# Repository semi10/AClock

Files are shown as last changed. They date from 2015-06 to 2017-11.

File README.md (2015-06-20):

AClock - Dot Matrix Display Information Board
Based on ATmega328P (Arduino)

Main Components:
Bicolor Red & Green LED 5mm Dot Matrix Display: http://store.sure-electronics.com/led/led-display/de-dp14211
RTC DS1307: http://datasheets.maximintegrated.com/en/ds/DS1307.pdf
EEPROM 24LC256: https://www.sparkfun.com/products/525
Humidity and Temperature Sensor RHT03: https://www.sparkfun.com/products/10167

Some Features:

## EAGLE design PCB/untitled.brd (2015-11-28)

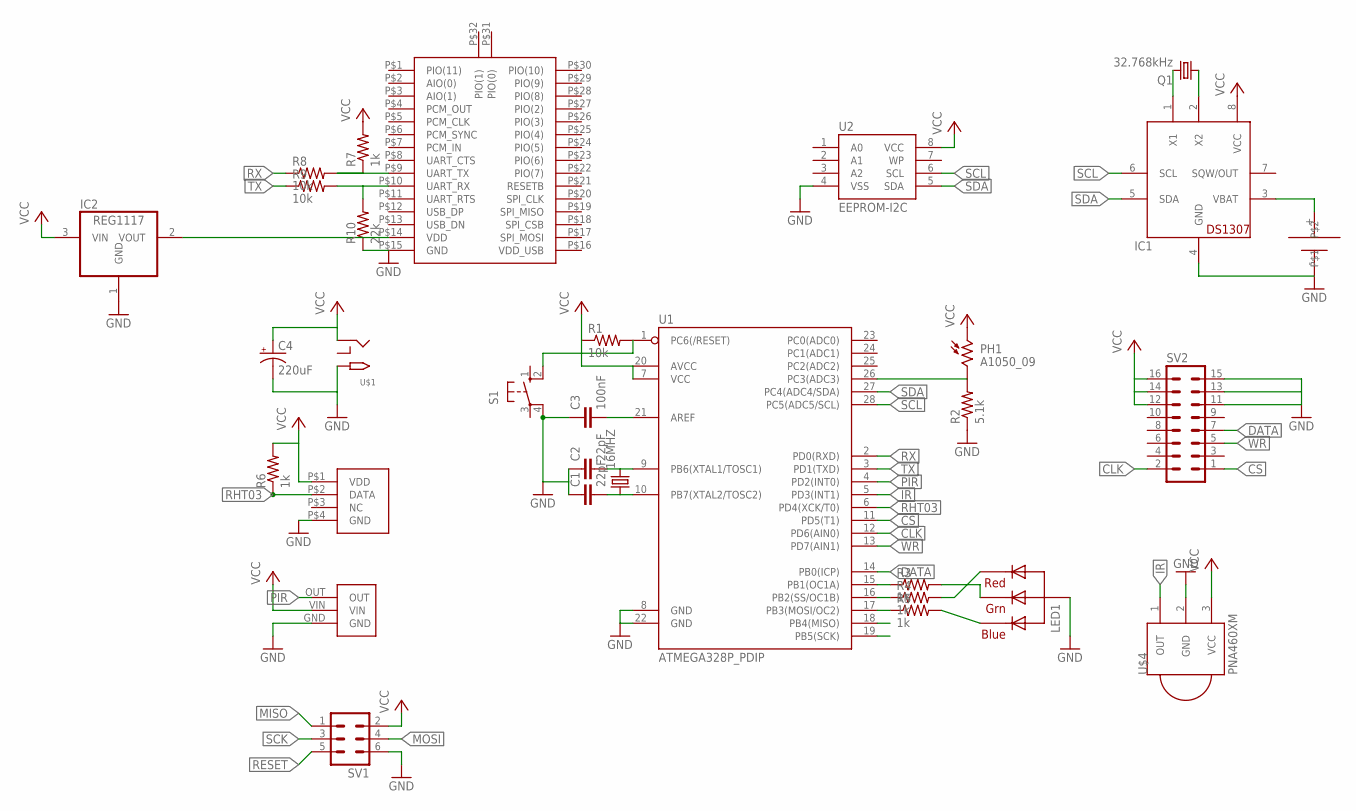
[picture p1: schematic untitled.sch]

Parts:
16MHZ: CRYSTALHC49U-H; HC49U-H
C1, C2: 22pF; C025-024X044
C3: 100nF; C025-024X044
C4: 220uF; E3,5-8
IC1: DS1307; DIL08
IC2: REG1117; SOT223
LED1: RGBLED_CA-5MM; LED5MMRGB
PH1: A1050_09; T0-46-A10XX
Q1: 32.768kHz; TC38H
R1, R8, R9: 10k; 0207/10
R2: 5.1k; 0207/10
R3, R4, R5, R6, R7: 1k; 0207/10
R10: 22k; 0207/10
S1: 10-XX; B3F-10XX
SV1: ML6
SV2: ML16
U1: ATMEGA328P_PDIP; DIL28-3
U2: EEPROM-I2C; DIL08
U$1: 2.1MMJACK; 2.1MMJACK_BREADBOARD
U$2: RHT03THROUGH_HOLE; RHT03
U$3: PIR_PM-6; PIR_THROUGHHOLE
U$4: PNA460XM
U$5: CR2032; CR2032-THM
U$6: BTM-182

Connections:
CLK: SV2.2, U1.12 (PD6(AIN0))
CS: SV2.1, U1.11 (PD5(T1))
DATA: SV2.7, U1.14 (PB0(ICP))
GND: C1.1, C2.1, C3.1, C4.-, IC1.4 (GND), IC2.1 (GND), LED1.2 (VCC), R2.1, R10.1, S1.4 (P1), SV1.6, SV2.11, SV2.13, SV2.15, U1.8 (GND), U1.22 (GND), U2.4 (VSS), U$1.GND (TIP), U$2.P$4 (GND), U$3.GND, U$4.2 (GND), U$5.-, U$6.P$15 (GND)
IR: U1.5 (PD3(INT1)), U$4.1 (OUT)
MISO: SV1.1, U1.18 (PB4(MISO))
MOSI: R5.1, SV1.4, U1.17 (PB3(MOSI/OC2))
unnamed: 16MHZ.1, C1.2, U1.10 (PB7(XTAL2/TOSC2))
unnamed: 16MHZ.2, C2.2, U1.9 (PB6(XTAL1/TOSC1))
unnamed: C3.2, U1.21 (AREF)
unnamed: R4.1, U1.16 (PB2(SS/OC1B))
unnamed: R3.1, U1.15 (PB1(OC1A))
unnamed: PH1.2, R2.2, U1.26 (PC3(ADC3))
unnamed: IC1.3 (VBAT), U$5.+
unnamed: IC2.2 (VOUT), U$6.P$14 (VDD)
unnamed: LED1.1 (RED), R4.2
unnamed: LED1.3 (GREEN), R3.2
unnamed: LED1.4 (BLUE), R5.2
unnamed: IC1.1 (X1), Q1.2
unnamed: IC1.2 (X2), Q1.1
unnamed: R7.1, R8.2, U$6.P$9 (UART_TX)
unnamed: R9.2, R10.2, U$6.P$10 (UART_RX)
PIR: U1.4 (PD2(INT0)), U$3.OUT
RESET: R1.2, S1.2 (S1), SV1.5, U1.1 (PC6(/RESET))
RHT03: R6.1, U1.6 (PD4(XCK/T0)), U$2.P$2 (DATA)
RX: R8.1, U1.2 (PD0(RXD))
SCK: SV1.3, U1.19 (PB5(SCK))
SCL: IC1.6 (SCL), U1.28 (PC5(ADC5/SCL)), U2.6 (SCL)
SDA: IC1.5 (SDA), U1.27 (PC4(ADC4/SDA)), U2.5 (SDA)
TX: R9.1, U1.3 (PD1(TXD))
VCC: C4.+, IC1.8 (VCC), IC2.3 (VIN), PH1.1, R1.1, R6.2, R7.2, SV1.2, SV2.12, SV2.14, SV2.16, U1.7 (VCC), U1.20 (AVCC), U2.8 (VCC), U$1.PWR (RING), U$2.P$1 (VDD), U$3.VIN, U$4.3 (VCC)
WR: SV2.5, U1.13 (PD7(AIN1))

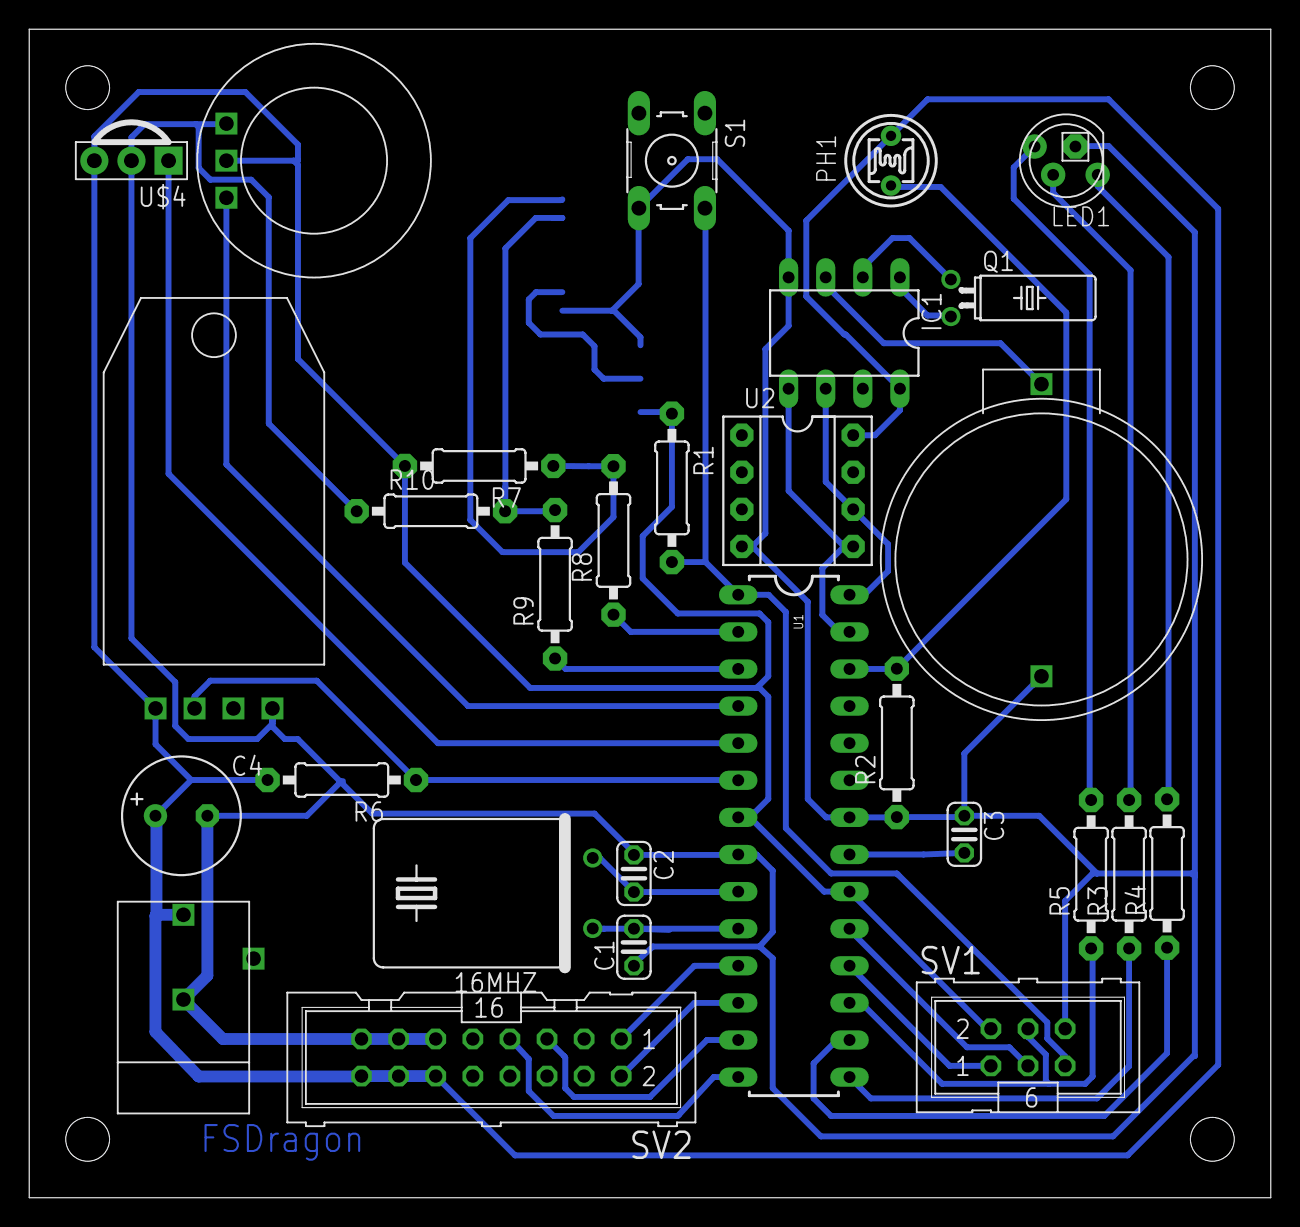
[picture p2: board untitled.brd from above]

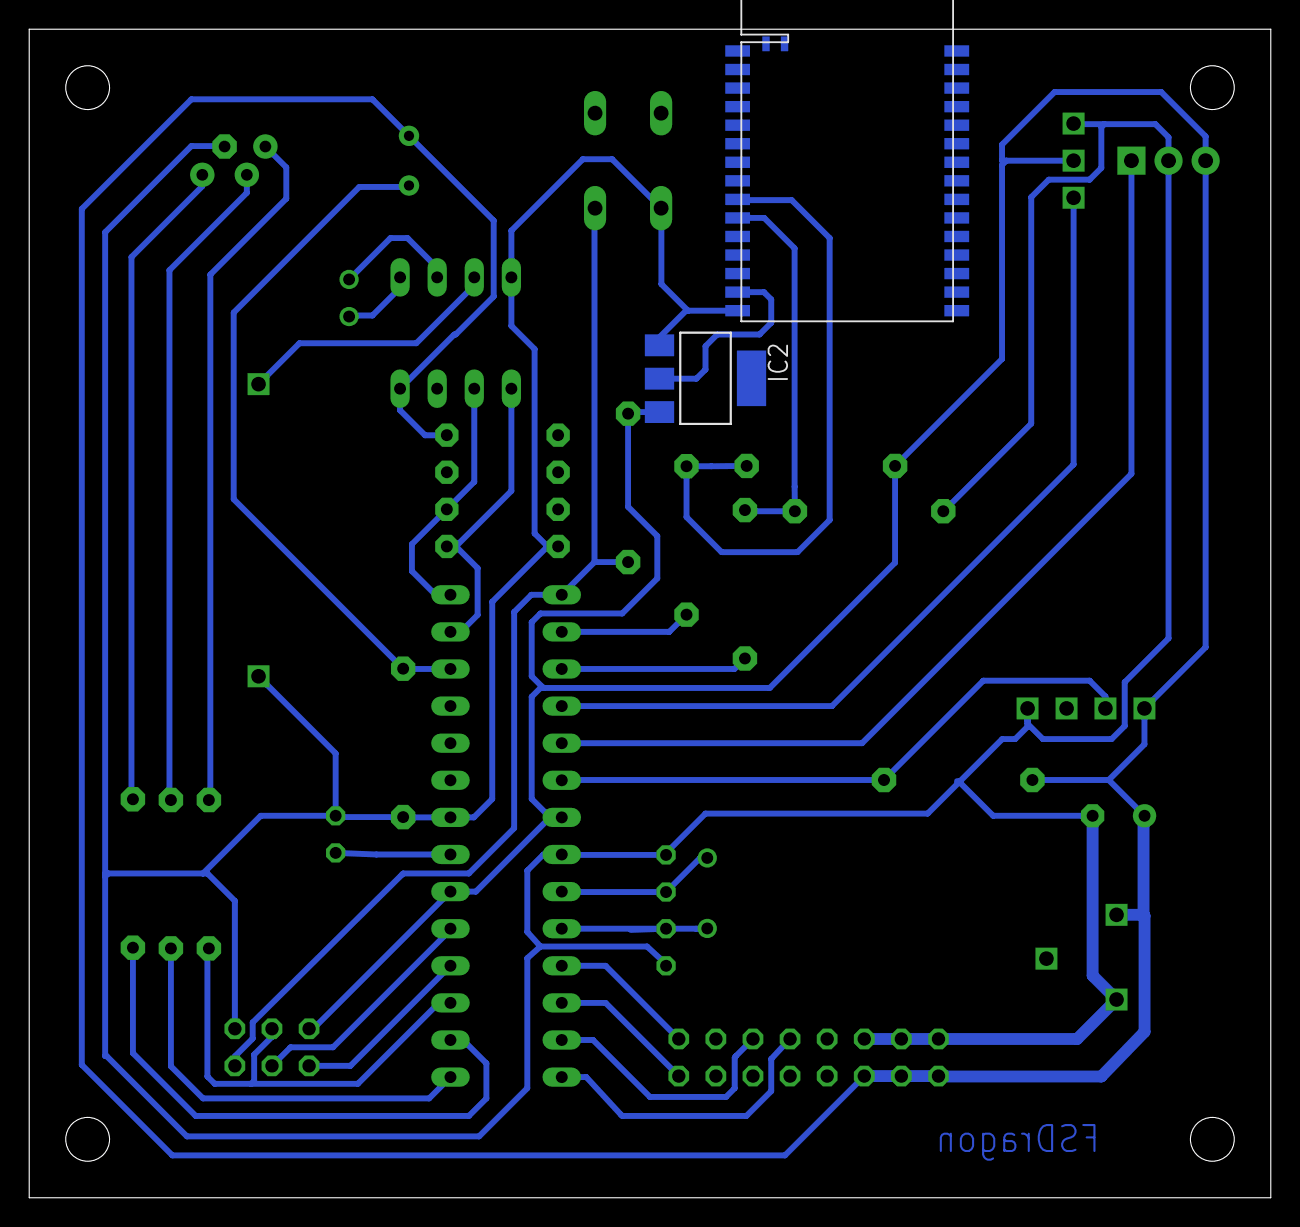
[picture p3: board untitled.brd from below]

Board: 1 copper layer, 85.0 x 80.0 mm, 31 parts (2 on the bottom side), 32 nets.

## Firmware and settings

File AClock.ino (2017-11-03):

#include <EEPROM.h>
#include <Wire.h>
#include <avr/wdt.h>
#include <avr/io.h>
#include "RTClib.h"
#include "I2CRom.h"
#include "ht1632c.h"
#include "RHT03.h"
#include "IR.h"
#include "ProgressBar.h"


#define IRpin 3   //Digital
#define LDRPin 3  //Analog
#define red 9
#define green 10
#define blue 11
#define bluetoothStatus 16

ht1632c Board1(5, 6, 7, 0); //(CS, CLK, WR, DATA, NC, NC, GND, VCC) -> (CS,CLK,WR - Port D , DATA - Port B)
RHT03 TH(4);  //Temperature & Humidity sensor
RTClib RTC;   //Real Time Clock
I2CRom Rom;
IR  IR1(IRpin);                  // IR remote
ProgressBar ProgressBar1(&Board1);
boolean statusLed[3] = {0, 1, 0}; // [R,G,B]
boolean sleep = false;
volatile boolean standBy = false;    //No movement registered in last ~20 minutes

boolean DateMode = false;
boolean HumidityMode = true;
boolean TemperatureMode = true;

void setup() {
  Serial.begin(19200);
  Board1.resetBoard();
  attachInterrupt(digitalPinToInterrupt(IRpin), initIRInterrupt, CHANGE);  //PIR
  pinMode(bluetoothStatus, INPUT);
  Board1.print("Debug", 0, 'g');
  delay(5000);
}

void loop() {

  UpdateTime();

  if (IR1.available()){
    receiveIR();
  }
  if (bluetoothStatus){
    
  }
  
  adjustBrightness();

  if (Board1.scrolling) Board1.scroll(1, 100);
  else if (!standBy) ModeSelect();

  if (Serial.available() > 0) getData();
  if (ProgressBar1.getInProgress()) ProgressBar1.animateProgress();

}

/******************************************************************
    Update Time and date on Display (if it turned on)
*/
void UpdateTime() {
  static unsigned long lastTimeUpdate;
  String time, hour, minute;
  static int column; // colon column

  //Executed each minute
  if (RTC.timeChanged()) {

    RTC.getTime(hour, minute);
    time = hour + ':' + minute;
    column = Board1.print(time , 0 , 'g', ':');
    blink(column, true);

    // Turn on display in the morning
    if (hour == "06" && minute == "40" && standBy == true) {
      sleep = false;
      if (!standBy) Board1.turnOn();
    }

    if (RTC.getMinute() == 0) log(); //Write to log each hour

    lastTimeUpdate = millis();

    ProgressBar1.redraw();
    //    //Progress Bar refresh
    //    if (progressBar != 0) {
    //      int tempBar = progressBar;
    //      progressBar = 0;
    //      updateProgress(tempBar);
    //    }

  }
  else if (abs(millis() - lastTimeUpdate) > 62000) {
    Board1.print("??:??", 0, 'r');
  }
  else {
    blink(column, false);
  }



}


/******************************************************************
    Select which data to show
*/
void ModeSelect() {
  static byte Mode;
  static unsigned long lastModeChange;

  if (abs(millis() - lastModeChange) > 3000) {
    lastModeChange = millis();

    for (int m = 0; m < 4; m++) {
      if (Mode == 0 && DateMode) {
        Board1.print(RTC.getDate(), 1, 'g');
        Mode++;
        break;
      }
      else if (Mode == 1 && HumidityMode) {
        Board1.print("H:" + (String)TH.getHumidity() + "%" , 1, 'g');
        Mode++;
        break;
      }
      else if (Mode == 2 && TemperatureMode) {
        Board1.print("T:" + (String)TH.getTemperature() + "C", 1, 'g');
        Mode++;
        break;
      }
      else {
        Mode++;
        if (Mode > 2) Mode = 0;
      }
    }
  }
}

/******************************************************************
    Get Data from Serial Port
*/

void getData() {
  String serIn;
  char character;
  char temp[3]; //for string to number convertion


    while (Serial.available()) {
      delay(6);
      character = Serial.read();
      serIn.concat(character);
      if (character == '\n') break;
    }

  Serial.println(serIn);

  if (serIn.startsWith("c:")) { //c: for clock adjust - Time Format: "c: dd/mm/yy hh:mm:ss PM" <-(or AM)
    RTC.setTime(serIn);
  }
  else if (serIn.startsWith("c?")) {
    Serial.print(RTC.getDay());
    Serial.print("/");
    Serial.print(RTC.getMonth());
    Serial.print("/");
    Serial.print(RTC.getYear());
    Serial.print(" ");
    Serial.print(RTC.getHour());
    Serial.print(":");
    Serial.print(RTC.getMinute());
    Serial.print(":");
    Serial.println(RTC.getSec());
  }
  else if (serIn.startsWith("p:")) { //p: for print text
    if (serIn.lastIndexOf('\r') != -1) serIn.remove(serIn.lastIndexOf('\r')); //remove new line char
    Board1.print(serIn.substring(3, serIn.length()), 1, 'g');
  }
  else if (serIn.startsWith("m?")) { //m? for mode check
    delay(100);
    Serial.println("mode: " + String(DateMode |  (HumidityMode << 1) | (TemperatureMode << 2), BIN));
  }
  else if (serIn.startsWith("m:")) { //m: for mode change
    serIn = serIn.substring(3, serIn.length());
    serIn.toCharArray(temp, serIn.length() + 1);
    DateMode = atoi(temp) & 1;
    HumidityMode = atoi(temp) & 2;
    TemperatureMode = atoi(temp) & 4;
  }
  else if (serIn.startsWith("\r\nCONNECT")) {
    statusLed[0] = 0;  //R
    statusLed[1] = 0;  //G
    statusLed[2] = 1;  //B
  }
  else if (serIn.startsWith("\r\nDISCONNECT")) {
    statusLed[0] = 0;  //R
    statusLed[1] = 1;  //G
    statusLed[2] = 0;  //B
    ProgressBar1.clear();
    ProgressBar1.setInProgress(false);
  }
  else if (serIn.startsWith("rom?")) {  //rom? for rom read
    int progress = 0;
    Board1.print("R.O.M", 0, 'g');
    Board1.print("Read", 1, 'g');
    for (int day = 0; day < 642; day++) { //day < 642
      for (int column = 0; column < 51; column++) {
        Serial.print(Rom.read(day * 51 + column));
        Serial.print(" ");

        if ((day * 51 + column) % 512 == 0) {
          if (progress < 32) Board1.point(progress, 7, 'r');
          else Board1.point(progress - 32, 7, 'o');
          progress += 1;
        }
      }
      Serial.println();
    }
    Board1.resetBoard();
    Board1.print(RTC.getTime(), 0, 'g');
  }
  else if (serIn.startsWith("t:")) { //t: for time (progress bar)
    int newVal = serIn.substring(3, serIn.length()).toInt();
    if (newVal < ProgressBar1.getVal()) ProgressBar1.clear();
    ProgressBar1.set(newVal);
  }
  else if (serIn.startsWith("s:")) { //s: for state (play/pause/stop)
    int state = serIn.substring(3, serIn.length()).toInt();

    switch (state) {
      case 0: //Stopped
        ProgressBar1.setInProgress(false);
        ProgressBar1.clear();
        break;
      case 1: //Paused
        ProgressBar1.setInProgress(false);
        ProgressBar1.redraw();
        break;
      case 2: //Playing
        ProgressBar1.setInProgress(true);
        break;
    }
  }
}

/******************************************************************
    Write temperature & humidity values to ROM
*/
void log() {
  int address = 0x00;
  int startDay = Rom.read(0x00);
  int startMonth = Rom.read(0x01);
  int startYear = Rom.read(0x02);
  int currentHour = RTC.getHour();
  int currentDay = RTC.getDay();
  int currentMonth = RTC.getMonth();
  int currentYear = RTC.getYear();
  int current_date2days = RTC.date2days(currentDay, currentMonth, currentYear);
  int start_date2days = RTC.date2days(startDay, startMonth, startYear);

  if (startDay > 31 || startDay < 0 || startMonth > 12 || startMonth < 0 || startYear > 99 || startYear < 15 || //Junk data
      address > 32741 || current_date2days < start_date2days) {  //Rom memory exceeded or time error
    address = 0x00;
  }
  else {
    address = (RTC.date2days(currentDay, currentMonth, currentYear) - RTC.date2days(startDay, startMonth, startYear)) * 51;
  }

  if ((Rom.read(address) != currentDay) || (Rom.read(address + 1) != currentMonth) || (Rom.read(address + 2) != currentYear)) { //Clean row for new data
    Rom.write(address, currentDay);
    Rom.write(address + 1, currentMonth);
    Rom.write(address + 2, currentYear);

    for (int i = address + 3; i < 51; i++) {
      Rom.write(i, 0xff);
    }
  }

  address += currentHour * 2 + 3;

  Rom.write(address, TH.getTemperature());
  Rom.write(address + 1, TH.getHumidity());
}

/******************************************************************
     Creates 2 blinking Dots to show the activity of the clock
     column - of blinking dots
     sync - to syncronize time update with blinking
*/
void blink(int column, bool sync) {
  static unsigned long lastBlink;

  if (millis() - lastBlink < 500) {
    Board1.point(column, 2, 'g');
    Board1.point(column, 4, 'g');
  }
  else if (millis() - lastBlink > 1000 || sync) {
    lastBlink = millis();
  }
  else {
    Board1.point(column, 2, 'b');
    Board1.point(column, 4, 'b');
  }
}


/******************************************************************
     Adjust brightness of the board & status LED by reading ambient light sensor
*/
void  adjustBrightness() {
  static unsigned long lastCheck;
  byte PWMBoard, PWMLed;

  if (millis() - lastCheck < 1000) return;
  int LDR = analogRead(LDRPin);

  PWMBoard = map(LDR, 0, 1024, 0, 15);
  Board1.setBrightness(PWMBoard);

  PWMLed = map(LDR, 0, 1024, 1, 30);
  analogWrite(red, statusLed[0] * PWMLed);
  analogWrite(green, statusLed[1] * PWMLed);
  analogWrite(blue, statusLed[2] * PWMLed);

  lastCheck = millis();
}


/******************************************************************
     Go to stand by mode OR wake Up
*/

void goToStandBy() {
  standBy = true;
  attachInterrupt(0, wakeUp, RISING);
  Board1.turnOff();
}

void wakeUp() {
  standBy = false;
  attachInterrupt(0, goToStandBy, FALLING);
  if (!sleep) Board1.turnOn();
}

/******************************************************************
     Receive IR signal
*/
void receiveIR() {
  // char IRcommand;
  // IRcommand =  IR.receive();

  switch (IR1.getCommand()) {
    case 'P':
      static unsigned long lastPress;
      if (millis() - lastPress > 500) {
        lastPress = millis();
        if (sleep) {
          sleep = false;
          if (!standBy) Board1.turnOn();
        }
        else {
          sleep = true;
          Board1.turnOff();
        }
      }
      break;
    case 'L':
      Serial.print("L");    //Louder
      break;
    case 'Q':
      Serial.print("Q");     //Quiet
      break;
    case '+':
      Serial.print("+");
      break;
    case '-':
      Serial.print("-");
      break;
      // default:
      // Serial.println("Error");   //Error
  }

}

//Init IR Interrupt
void initIRInterrupt(){
  IR1.receiveBit();
}

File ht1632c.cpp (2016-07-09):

/******************************************************************
   Nov, 2008 by Bill Westfield ("WestfW")
   Copyrighted and distributed under the terms of the Berkely license
   (copy freely, but include this notice of original author.)

   May, 2011 edited by Semion Faifman for SURE electronics 32X16 RG Bicolor LED Dot Matrix Unit Board
*/
#include "ht1632c.h"                     // Holtek LED driver by WestFW - updated to HT1632C by Nick Hall
#include <avr/pgmspace.h>                // Enable data to be stored in Flash Mem as well as SRAM              
#include "NewFont.h"                     // Font library
#include <Arduino.h>
#define led1 8
#define led2 9
#define led3 10
#define led4 11

ht1632c::ht1632c(byte ht1632_cs, byte ht1632_clk, byte ht1632_wrclk, byte ht1632_data) {
  _ht1632_cs = ht1632_cs;		//Chip select signal input
  _ht1632_clk = ht1632_clk;		//Chip select clock signal input
  _ht1632_wrclk = ht1632_wrclk;	        //Write data clock input
  _ht1632_data = ht1632_data;		//Data input

  DDRD |= (1 << _ht1632_cs);       //ht1632_cs as output
  DDRD |= (1 << _ht1632_clk);      //_ht1632_clk as output
  DDRD |= (1 << _ht1632_wrclk);    //_ht1632_wrclk as output
  DDRB |= (1 << _ht1632_data);     //_ht1632_data as output
  //pinMode(_ht1632_cs, OUTPUT);
  // pinMode(_ht1632_clk, OUTPUT);
  // pinMode(_ht1632_wrclk, OUTPUT);
  // pinMode(_ht1632_data, OUTPUT);


  for (int chip = 0; chip < 4; chip++) {
    sendCmd(chip, HT1632_CMD_SYSON);    // System on
    sendCmd(chip, HT1632_CMD_LEDON);    // LEDs on
    sendCmd(chip, HT1632_CMD_COMS00);   // NMOS Output 8 COM X 16 Rows X 2 Colors
    sendCmd(chip, HT1632_CMD_PWM + 5);
    sendCmd(chip, HT1632_CMD_SYSDIS);
    sendCmd(chip, HT1632_CMD_SYSON);
  }

  scrolling = false;
  resetBoard();
}

/******************************************************************
   Select or de-select a particular ht1632c chip.
   CD pins are active-low; writing 0 to the pin selects the chip.
*/
void ht1632c::chipSelect(byte chip) {
  PORTD &= ~(B00000001 << _ht1632_cs);   //cs-LOW:   Writes '0' to shift register
  PORTD &= ~(B00000001 << _ht1632_clk);  //clk-LOW:  Activates first Chip
  PORTD |= B00000001 << _ht1632_clk;     //clk-HIGH
  PORTD |= B00000001 << _ht1632_cs;      //cd-HIGH:  Writes '1' to shift register to disable other chips

  for (activeChip = 0 ; activeChip < chip; activeChip++) {  //Shift '0' to specific chip to enable it
    PORTD &= ~(B00000001 << _ht1632_clk); //clk-LOW
    PORTD |= B00000001 << _ht1632_clk;    //clk-HIGH
  }
}

void ht1632c::chipFree() {
  PORTD |= B00000001 << _ht1632_cs; //cs-HIGH: Reset Selected Chips

  for (byte i = 0; i < 4; i++) {    //4 for 1 board only (8 for 2)
    PORTD &= ~(B00000001 << _ht1632_clk); //clk-LOW
    PORTD |= B00000001 << _ht1632_clk;    //clk-HIGH
  }

}

/******************************************************************
   sendcmd
   Send a command to the ht1632 chip. A command consists of a 3-bit "CMD" ID, an 8bit command, and one "don't care bit".
     Select 1 0 0 c7 c6 c5 c4 c3 c2 c1 c0 xx Free
*/
void ht1632c::sendCmd (byte chip, byte command)
{
  chipSelect(chip); // Select chip
  writeBits(HT1632_ID_CMD, 1 << 2);         // send 3 bits of id: COMMMAND
  writeBits(command, 1 << 7);               // send the actual command
  writeBits(0, 1);         	            // one extra dont-care bit in commands.
  chipFree();
}

/******************************************************************
   senddata
   send a nibble (4 bits) of data to a particular memory location of the
   ht1632.  The command has 3 bit ID, 7 bits of address, and 4 bits of data.
      Select 1 0 1 A6 A5 A4 A3 A2 A1 A0 D0 D1 D2 D3 Free
   Note that the address is sent MSB first, while the data is sent LSB first!
   This means that somewhere a bit reversal will have to be done to get
   zero-based addressing of words and dots within words.
*/
void ht1632c::sendData (byte chip, byte address, byte data) {
  chipSelect(chip); // Select chip
  writeBits(HT1632_ID_WR, 1 << 2);           // Send ID: WRITE to RAM
  writeBits(address, 1 << 6);                // Send address
  writeBits(data, 1 << 3);                   // Send 4 bits of data
  chipFree();
}

/******************************************************************
   ht1632_writebits
   Write bits (up to 8) to h1632 on pins ht1632_data, ht1632_wrclk Chip is assumed to already be chip-selected
   Bits are shifted out from MSB to LSB, with the first bit sent being (bits & firstbit), shifted till firsbit is zero.
*/
void ht1632c::writeBits (byte bits, byte firstbit)
{
  while (firstbit) {
    PORTD &= ~(B00000001 << _ht1632_wrclk);    //wrclk-LOW

    if (bits & firstbit) {
      PORTB |= B00000001 << _ht1632_data;      //data-HIGH
    }
    else {
      PORTB &= ~(B00000001 << _ht1632_data);  //data-LOW
    }
    PORTD |= B00000001 << _ht1632_wrclk;    //wrclk-HIGH
    firstbit >>= 1;
  }
}
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

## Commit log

2015-06-20 IR receiver + Temperature & Humidity data logger + Ambient light sensor
2015-09-08 PCB development & minor code updates
2015-11-28 Eagle files add
    [untitled.brd, untitled.sch]
2016-07-09 Print mechanism changed

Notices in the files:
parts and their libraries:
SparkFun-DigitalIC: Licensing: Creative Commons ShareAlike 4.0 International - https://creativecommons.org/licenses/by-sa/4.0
